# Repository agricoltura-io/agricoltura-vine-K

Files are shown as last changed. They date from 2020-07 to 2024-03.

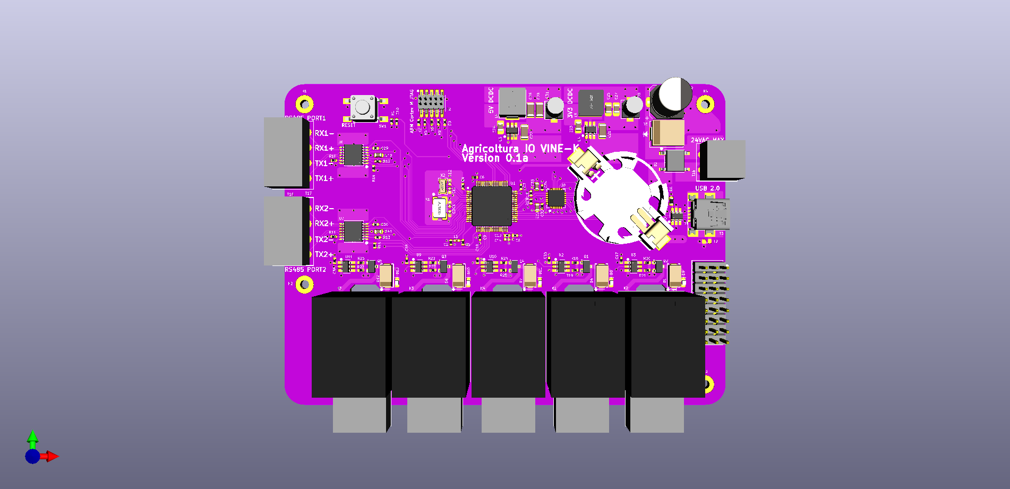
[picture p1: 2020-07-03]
PCB/agricoltura-vine-k/agricoltura-vine-k3D.png

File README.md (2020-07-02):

# agricoltura-vine-K
daisy chainable interface for relay control of high voltage devices for various agriculture applications, wired RS485 system, powered by 24VAC

Quick Specs:
- ST Microelectronics STM32F446RET6 ARM Cortex M4F 180MHZ MCU
- 5V Tolerant Analog Inputs
- 8x I2C interfaces
- 4x UART interface (via mux)
- 8x 5V digital IO ports
- 2x G5LE-14 DC5 SPDT Relays
- USB 2.0 connectivity
- RS485 port
- 24VAC power input
- 2A 3.3V DCDC Regulator, for supporting lots of sensors
- 2A 5V DCDC Regulator, for 5V IO and other devices

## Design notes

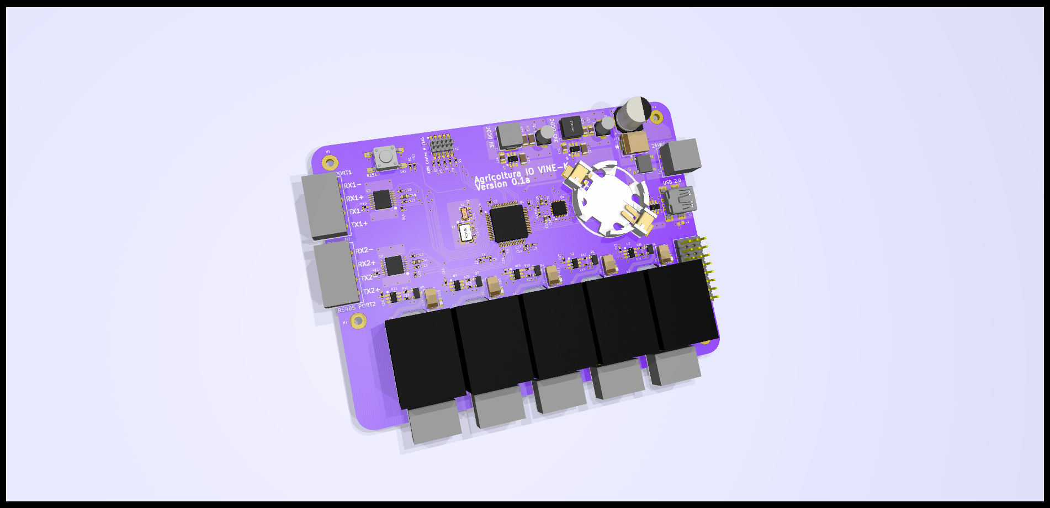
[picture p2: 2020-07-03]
PCB/agricoltura-vine-k/agricoltura-vine-k3DRay.png

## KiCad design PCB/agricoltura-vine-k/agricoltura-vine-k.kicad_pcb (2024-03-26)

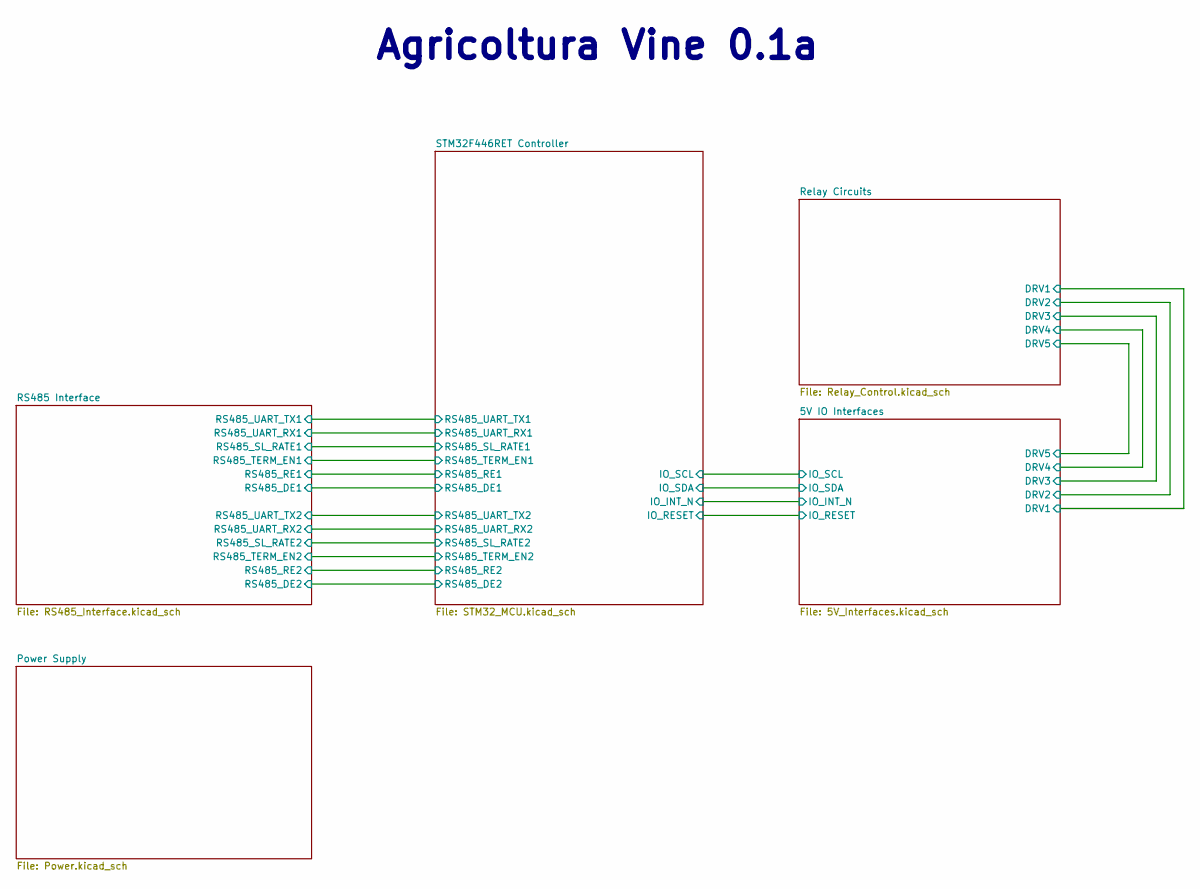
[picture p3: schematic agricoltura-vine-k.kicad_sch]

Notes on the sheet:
Agricoltura Vine 0.1a

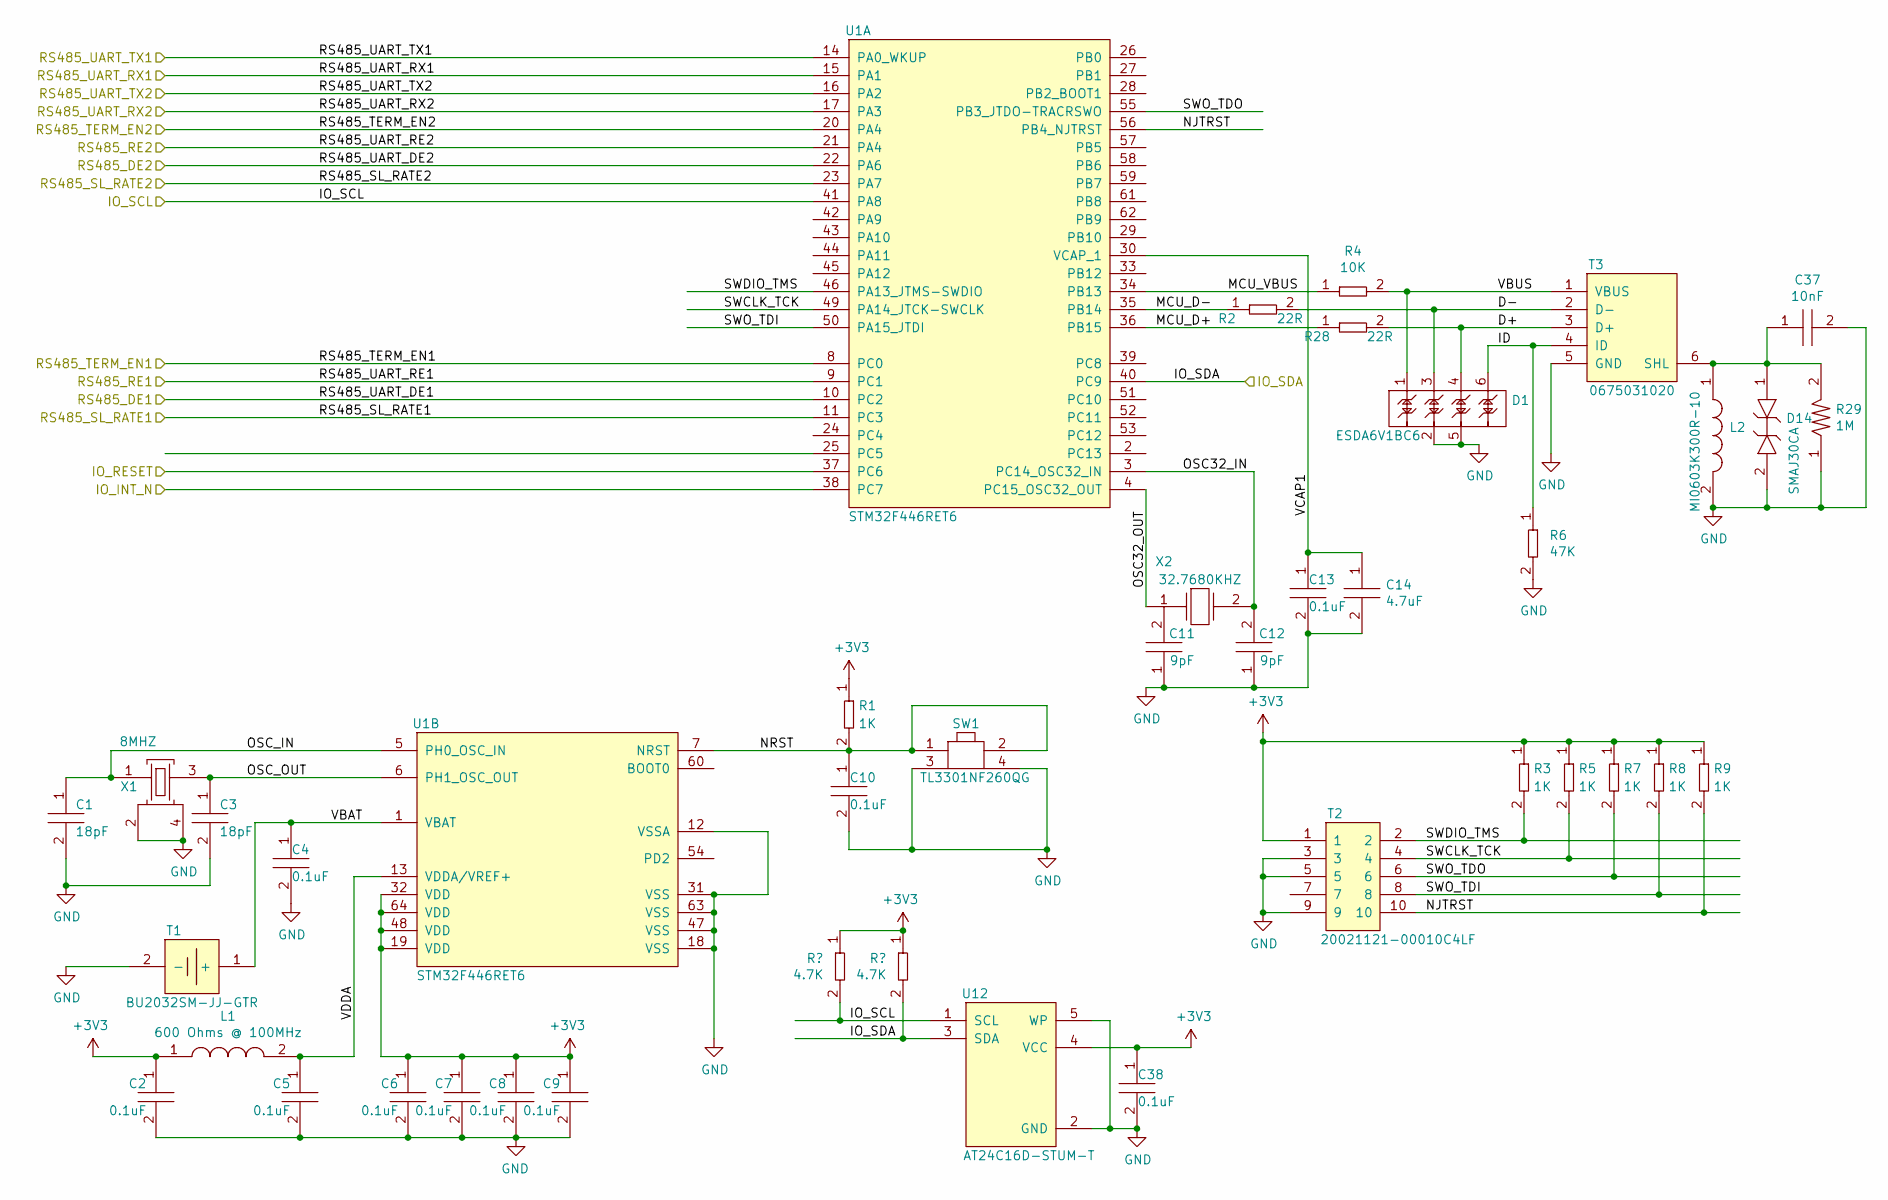
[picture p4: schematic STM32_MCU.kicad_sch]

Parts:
C1, C3: GCM1555C1H180GA16D; C0402; Tolerance 2%; Voltage 50V; MFR# GCM1555C1H180GA16D
C2, C4, C5, C6, C7, C8, C9, C10, C13, C38: C0402C104K9PACTU; R0402; Tolerance 10%; Voltage 6.3V; MFR# C0402C104K9PACTU
C11, C12: CL05C090CB5NNNC; C0402; Tolerance ±0.25pF; Voltage 50V; MFR# CL05C090CB5NNNC
C14: GRM155R60J475ME47D; C0402; Tolerance 20%; Voltage 6.3V; MFR# GRM155R60J475ME47D
C37: C0805C103KCRACAUTO; C0805; Tolerance 10%; Voltage 500V; MFR# C0805C103KCRACAUTO
D1: ESDA6V1BC6; SOT-23-6_Handsoldering; Tolerance *; Voltage 5V/6.1VBreakdown; MFR# ESDA6V1BC6
D14: SMAJ30CA; Tolerance *; Voltage 30V Clamp; MFR# SMAJ30CA
L1: BLM15HG601SN1D; Tolerance *; Voltage *; MFR# BLM15HG601SN1D
L2: MI0603K300R-10; Tolerance *; Voltage *; MFR# MI0603K300R-10
R1, R3, R5, R7, R8, R9: RC0402FR-071KL; R0402; Tolerance 1%; Voltage *; MFR# RC0402FR-071KL
R2, R28: RC0402FR-0722RL; R0402; Tolerance 1%; Voltage *; MFR# RC0402FR-0722RL
R4: RC0402FR-0710KL; R0402; Tolerance 1%; Voltage *; MFR# RC0402FR-0710KL
R6: RC0603FR-0747KL; R0603; Tolerance 1%; Voltage *; MFR# RC0603FR-0747KL
R29: RC1206FR-071ML; R1206; Tolerance 1%; Voltage *; MFR# RC1206FR-071ML
R30, R31: RC0402FR-074K7L; R0402; Tolerance 1%; Voltage *; MFR# RC0402FR-074K7L
SW1: TL3301NF260QG; Tolerance *; Voltage 12VDC; MFR# TL3301NF260QG
T1: BU2032SM-JJ-GTR; Tolerance *; Voltage 3.3V; MFR# BU2032SM-JJ-GTR
T2: 20021121-00010C4LF; Tolerance *; Voltage *; MFR# 20021121-00010C4LF
T3: 0675031020; USB_Mini-B; Tolerance *; Voltage 5V; MFR# 0675031020
U1: STM32F446RET6; Tolerance *; Voltage 1.7V ~ 3.6V; MFR# STM32F446RET6
U12: AT24C16D-STUM-T; SOT-23-5; Tolerance *; Voltage 3.3V; MFR# AT24C16D-STUM-T
X1: ABM3B-8.000MHZ-B2-T; ABM3B8.000MHZB2T; Tolerance *; Voltage *; MFR# ABM3B-8.000MHZ-B2-T
X2: ABS07-32.768KHZ-9-T; Tolerance *; Voltage *; MFR# ABS07-32.768KHZ-9-T

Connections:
+3V3: C2.1, C6.1, C7.1, C8.1, C9.1, C38.1, L1.1, R1.1, R3.1, R5.1, R7.1, R8.1, R9.1, R30.1, R31.1, T2.1, U1.19 (VDD), U1.32 (VDD), U1.48 (VDD), U1.64 (VDD), U12.4 (VCC); also elsewhere on the board
/5V IO Interfaces/IO_INT_N: U1.38 (PC7); also elsewhere on the board
/5V IO Interfaces/IO_RESET: U1.37 (PC6); also elsewhere on the board
/5V IO Interfaces/IO_SCL: R30.2, U1.41 (PA8), U12.1 (SCL); also elsewhere on the board
/5V IO Interfaces/IO_SDA: R31.2, U1.40 (PC9), U12.3 (SDA); also elsewhere on the board
/RS485 Interface/RS485_DE1: U1.10 (PC2); also elsewhere on the board
/RS485 Interface/RS485_DE2: U1.22 (PA6); also elsewhere on the board
/RS485 Interface/RS485_RE1: U1.9 (PC1); also elsewhere on the board
/RS485 Interface/RS485_RE2: U1.21 (PA4); also elsewhere on the board
/RS485 Interface/RS485_SL_RATE1: U1.11 (PC3); also elsewhere on the board
/RS485 Interface/RS485_SL_RATE2: U1.23 (PA7); also elsewhere on the board
/RS485 Interface/RS485_TERM_EN1: U1.8 (PC0); also elsewhere on the board
/RS485 Interface/RS485_TERM_EN2: U1.20 (PA4); also elsewhere on the board
/RS485 Interface/RS485_UART_RX1: U1.15 (PA1); also elsewhere on the board
/RS485 Interface/RS485_UART_RX2: U1.17 (PA3); also elsewhere on the board
/RS485 Interface/RS485_UART_TX1: U1.14 (PA0_WKUP); also elsewhere on the board
/RS485 Interface/RS485_UART_TX2: U1.16 (PA2); also elsewhere on the board
/STM32F446RET Controller/D+: D1.4, R28.2, T3.3 (D+)
/STM32F446RET Controller/D-: D1.3, R2.2, T3.2 (D-)
/STM32F446RET Controller/ID: D1.6, R6.1, T3.4 (ID)
/STM32F446RET Controller/MCU_D+: R28.1, U1.36 (PB15)
/STM32F446RET Controller/MCU_D-: R2.1, U1.35 (PB14)
/STM32F446RET Controller/MCU_VBUS: R4.1, U1.34 (PB13)
/STM32F446RET Controller/NJTRST: R9.2, T2.10, U1.56 (PB4_NJTRST)
/STM32F446RET Controller/NRST: C10.1, R1.2, SW1.1, SW1.2, U1.7 (NRST)
/STM32F446RET Controller/OSC32_IN: C12.2, U1.3 (PC14_OSC32_IN), X2.2
/STM32F446RET Controller/OSC32_OUT: U1.4 (PC15_OSC32_OUT), X2.1
/STM32F446RET Controller/OSC_IN: C1.1, U1.5 (PH0_OSC_IN), X1.1
/STM32F446RET Controller/OSC_OUT: C3.1, U1.6 (PH1_OSC_OUT), X1.3
/STM32F446RET Controller/SWCLK_TCK: R5.2, T2.4, U1.49 (PA14_JTCK-SWCLK)
/STM32F446RET Controller/SWDIO_TMS: R3.2, T2.2, U1.46 (PA13_JTMS-SWDIO)
/STM32F446RET Controller/SWO_TDI: R8.2, T2.8, U1.50 (PA15_JTDI)
/STM32F446RET Controller/SWO_TDO: R7.2, T2.6, U1.55 (PB3_JTDO-TRACRSWO)
/STM32F446RET Controller/VBAT: C4.1, T1.1 (+), U1.1 (VBAT)
/STM32F446RET Controller/VBUS: D1.1, R4.2, T3.1 (VBUS)
/STM32F446RET Controller/VCAP1: C13.1, C14.1, U1.30 (VCAP_1)
/STM32F446RET Controller/VDDA: C5.1, L1.2, U1.13 (VDDA/VREF+)
GND: C1.2, C2.2, C3.2, C4.2, C5.2, C6.2, C7.2, C8.2, C9.2, C10.2, C11.1, C12.1, C13.2, C14.2, C37.2, C38.2, D1.2, D1.5, D14.2, L2.2, R6.2, R29.1, SW1.3, SW1.4, T1.2 (-), T2.3, T2.5, T2.9, T3.5 (GND), U1.12 (VSSA), U1.18 (VSS), U1.31 (VSS), U1.47 (VSS), U1.63 (VSS), U12.2 (GND), U12.5 (WP), X1.2, X1.4; also elsewhere on the board
unnamed: C37.1, D14.1, L2.1, R29.2, T3.6 (SHL)

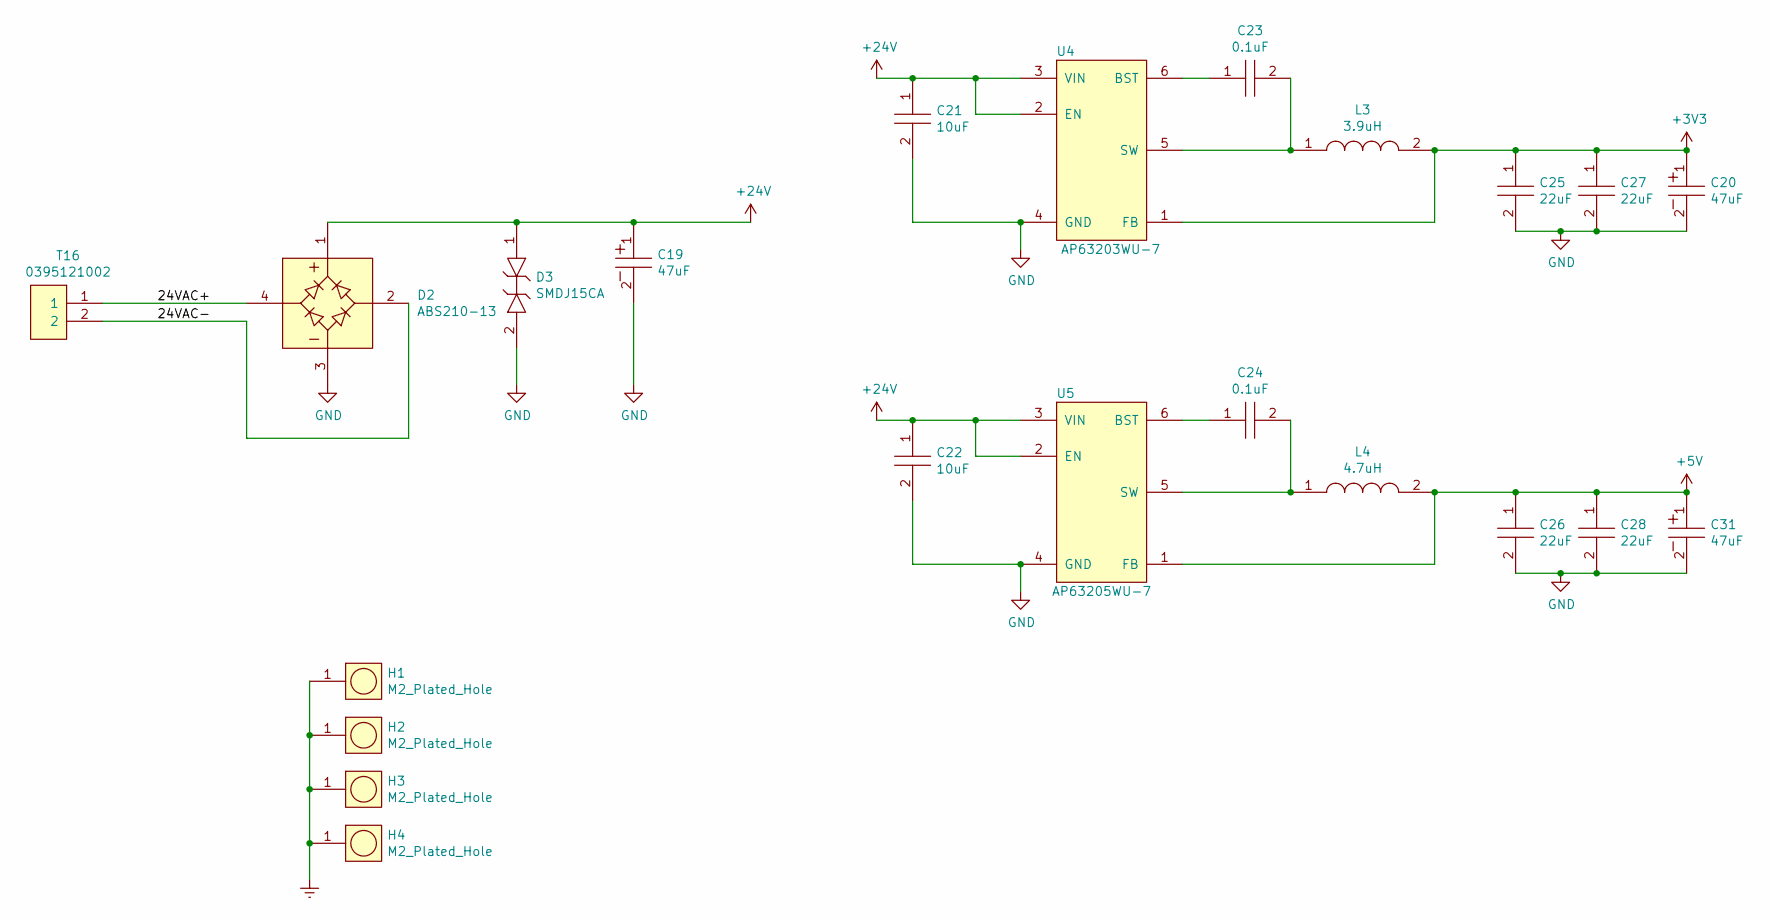
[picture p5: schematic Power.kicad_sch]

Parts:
C19: UUQ1H470MCL1GS; CP_Elec_8x10; Tolerance 20%; Voltage 50V; MFR# UUQ1H470MCL1GS
C20, C31: UCM1C470MCL1GS; Tolerance 20%; Voltage 16V; MFR# UCM1C470MCL1GS
C21, C22: GRT31CR61H106KE01L; C1206; Tolerance 10%; Voltage 50V; MFR# GRT31CR61H106KE01L
C23: C0805C104M5RACTU; C0805; Tolerance 20%; Voltage 50V; MFR# C0805C104M5RACTU
C24: C2012X7R2A104K125AA; C0805; Tolerance 10%; Voltage 100V; MFR# C2012X7R2A104K125AA
C25, C27: GRM21BD70J226ME44L; C0805; Tolerance 20%; Voltage 6.3v; MFR# GRM21BD70J226ME44L
C26, C28: GRT31CC81C226KE01L; C1206; Tolerance 10%; Voltage 16V; MFR# GRT31CC81C226KE01L
D2: ABS210-13; Tolerance *; Voltage 1KV 2A; MFR# ABS210-13
D3: SMDJ15CA; Tolerance *; Voltage 24V Clamp; MFR# SMDJ15CA
H1, H2, H3, H4: M2_Plated_Hole; M2_HOLE; Tolerance *; Voltage *; MFR# *
L3: ASPI-0628-3R9M-T1; Tolerance 20%; Voltage *; MFR# ASPI-0628-3R9M-T1
L4: SRP6540-4R7M; Tolerance 20%; Voltage *; MFR# SRP6540-4R7M
T16: 0395121002; Tolerance *; Voltage 300V; MFR# 0395121002
U4: AP63203WU-7; SOT-23-6_Handsoldering; Tolerance *; Voltage 32V, 3.3V; MFR# AP63203WU-7
U5: AP63205WU-7; SOT-23-6_Handsoldering; Tolerance *; Voltage 32V, 5V; MFR# AP63205WU-7

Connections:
+3V3: C20.1, C25.1, C27.1, L3.2, U4.1 (FB); also elsewhere on the board
+24V: C19.1, C21.1, C22.1, D2.1, D3.1, U4.2 (EN), U4.3 (VIN), U5.2 (EN), U5.3 (VIN)
/Power Supply/24VAC+: D2.4, T16.1
/Power Supply/24VAC-: D2.2, T16.2
Earth: H1.1, H2.1, H3.1, H4.1
GND: C19.2, C20.2, C21.2, C22.2, C25.2, C26.2, C27.2, C28.2, C31.2, D2.3, D3.2, U4.4 (GND), U5.4 (GND); also elsewhere on the board
unnamed: C23.1, U4.6 (BST)
unnamed: C23.2, L3.1, U4.5 (SW)
unnamed: C24.1, U5.6 (BST)
unnamed: C24.2, L4.1, U5.5 (SW)

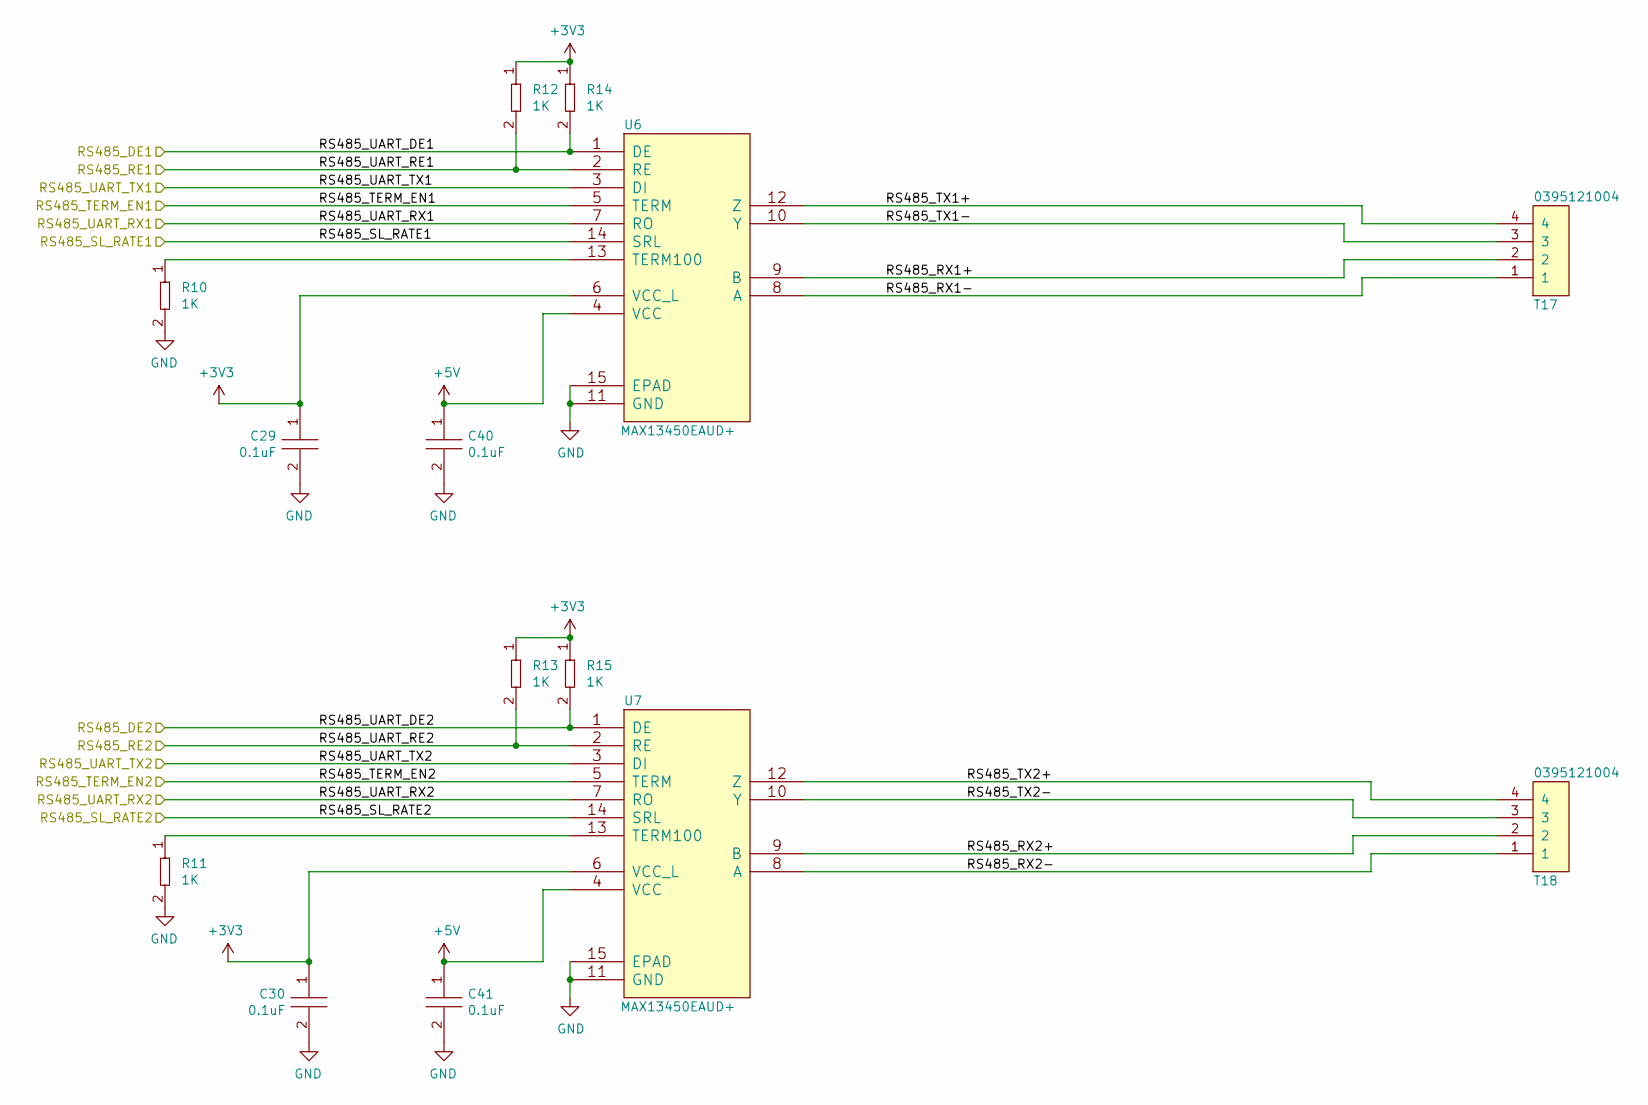
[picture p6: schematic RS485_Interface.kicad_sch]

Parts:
C29, C30: C0402C104K9PACTU; R0402; Tolerance 10%; Voltage 6.3V; MFR# C0402C104K9PACTU
C40, C41: CGA3E2X7R1H104K080AA; C0603; Tolerance 10%; Voltage 50V; MFR# CGA3E2X7R1H104K080AA
R10, R11, R12, R13, R14, R15: RC0402FR-071KL; R0402; Tolerance 1%; Voltage *; MFR# RC0402FR-071KL
T17, T18: 0395121004; Tolerance *; Voltage 300V; MFR# 0395121004
U6, U7: MAX13450EAUD+; MAX13450EAUD&plus_; Tolerance *; Voltage 4.75V ~ 5.25V; MFR# MAX13450EAUD+

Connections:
+3V3: C29.1, C30.1, R12.1, R13.1, R14.1, R15.1, U6.6 (VCC_L), U7.6 (VCC_L); also elsewhere on the board
/RS485 Interface/RS485_DE1: R14.2, U6.1 (DE); also elsewhere on the board
/RS485 Interface/RS485_DE2: R15.2, U7.1 (DE); also elsewhere on the board
/RS485 Interface/RS485_RE1: R12.2, U6.2 (RE); also elsewhere on the board
/RS485 Interface/RS485_RE2: R13.2, U7.2 (RE); also elsewhere on the board
/RS485 Interface/RS485_RX1+: T17.2, U6.9 (B)
/RS485 Interface/RS485_RX1-: T17.1, U6.8 (A)
/RS485 Interface/RS485_RX2+: T18.2, U7.9 (B)
/RS485 Interface/RS485_RX2-: T18.1, U7.8 (A)
/RS485 Interface/RS485_SL_RATE1: U6.14 (SRL); also elsewhere on the board
/RS485 Interface/RS485_SL_RATE2: U7.14 (SRL); also elsewhere on the board
/RS485 Interface/RS485_TERM_EN1: U6.5 (TERM); also elsewhere on the board
/RS485 Interface/RS485_TERM_EN2: U7.5 (TERM); also elsewhere on the board
/RS485 Interface/RS485_TX1+: T17.4, U6.12 (Z)
/RS485 Interface/RS485_TX1-: T17.3, U6.10 (Y)
/RS485 Interface/RS485_TX2+: T18.4, U7.12 (Z)
/RS485 Interface/RS485_TX2-: T18.3, U7.10 (Y)
/RS485 Interface/RS485_UART_RX1: U6.7 (RO); also elsewhere on the board
/RS485 Interface/RS485_UART_RX2: U7.7 (RO); also elsewhere on the board
/RS485 Interface/RS485_UART_TX1: U6.3 (DI); also elsewhere on the board
/RS485 Interface/RS485_UART_TX2: U7.3 (DI); also elsewhere on the board
GND: C29.2, C30.2, C40.2, C41.2, R10.2, R11.2, U6.11 (GND), U6.15 (EPAD), U7.11 (GND), U7.15 (EPAD); also elsewhere on the board
unnamed: R10.1, U6.13 (TERM100)
unnamed: R11.1, U7.13 (TERM100)

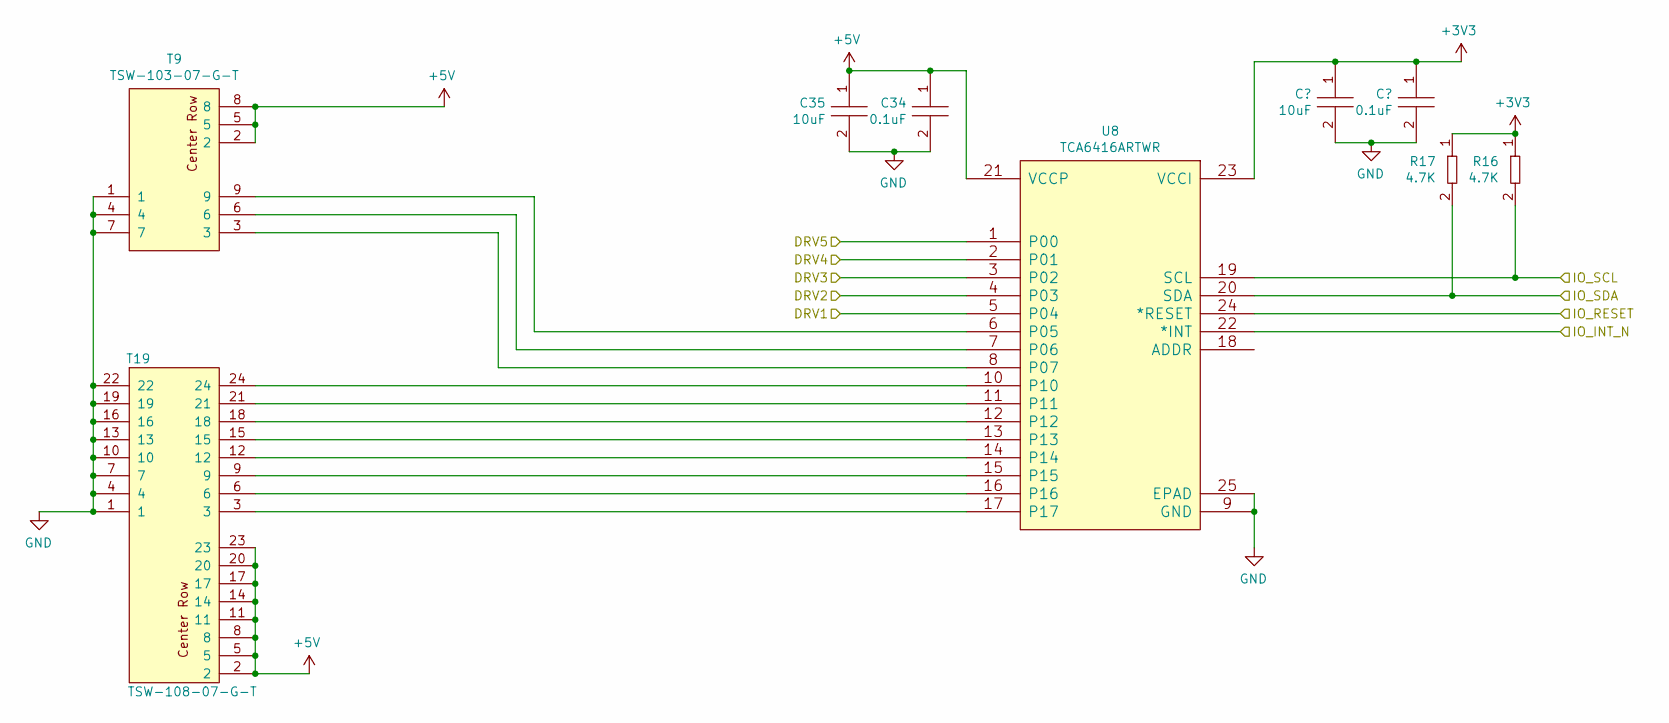
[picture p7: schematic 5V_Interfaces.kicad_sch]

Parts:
C32, C34: C0402C104K9PACTU; R0402; Tolerance 10%; Voltage 6.3V; MFR# C0402C104K9PACTU
C33, C35: GRM188R61A106KE69J; C0603; Tolerance 10%; Voltage 10V; MFR# GRM188R61A106KE69J
R16, R17: RC0402FR-074K7L; R0402; Tolerance 1%; Voltage *; MFR# RC0402FR-074K7L
T9: TSW-103-07-G-T; Tolerance *; Voltage *; MFR# TSW-103-07-G-T
T19: TSW-108-07-G-T; Tolerance *; Voltage *; MFR# TSW-108-07-G-T
U8: TCA6416ARTWR; Tolerance *; Voltage 1.65V ~ 5.5V; MFR# TCA6416ARTWR

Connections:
+3V3: C32.1, C33.1, R16.1, R17.1, U8.23 (VCCI); also elsewhere on the board
/5V IO Interfaces/DRV1: U8.5 (P04); also elsewhere on the board
/5V IO Interfaces/DRV2: U8.4 (P03); also elsewhere on the board
/5V IO Interfaces/DRV3: U8.3 (P02); also elsewhere on the board
/5V IO Interfaces/DRV4: U8.2 (P01); also elsewhere on the board
/5V IO Interfaces/DRV5: U8.1 (P00); also elsewhere on the board
/5V IO Interfaces/IO_INT_N: U8.22 (*INT); also elsewhere on the board
/5V IO Interfaces/IO_RESET: U8.24 (*RESET); also elsewhere on the board
/5V IO Interfaces/IO_SCL: R16.2, U8.19 (SCL); also elsewhere on the board
/5V IO Interfaces/IO_SDA: R17.2, U8.20 (SDA); also elsewhere on the board
GND: C32.2, C33.2, C34.2, C35.2, T9.1, T9.4, T9.7, T19.1, T19.4, T19.7, T19.10, T19.13, T19.16, T19.19, T19.22, U8.9 (GND), U8.25 (EPAD); also elsewhere on the board
unnamed: T9.3, U8.8 (P07)
unnamed: T9.6, U8.7 (P06)
unnamed: T9.9, U8.6 (P05)
unnamed: T19.3, U8.17
unnamed: T19.6, U8.16
unnamed: T19.9, U8.15
unnamed: T19.12, U8.14
unnamed: T19.15, U8.13
unnamed: T19.18, U8.12
unnamed: T19.21, U8.11
unnamed: T19.24, U8.10

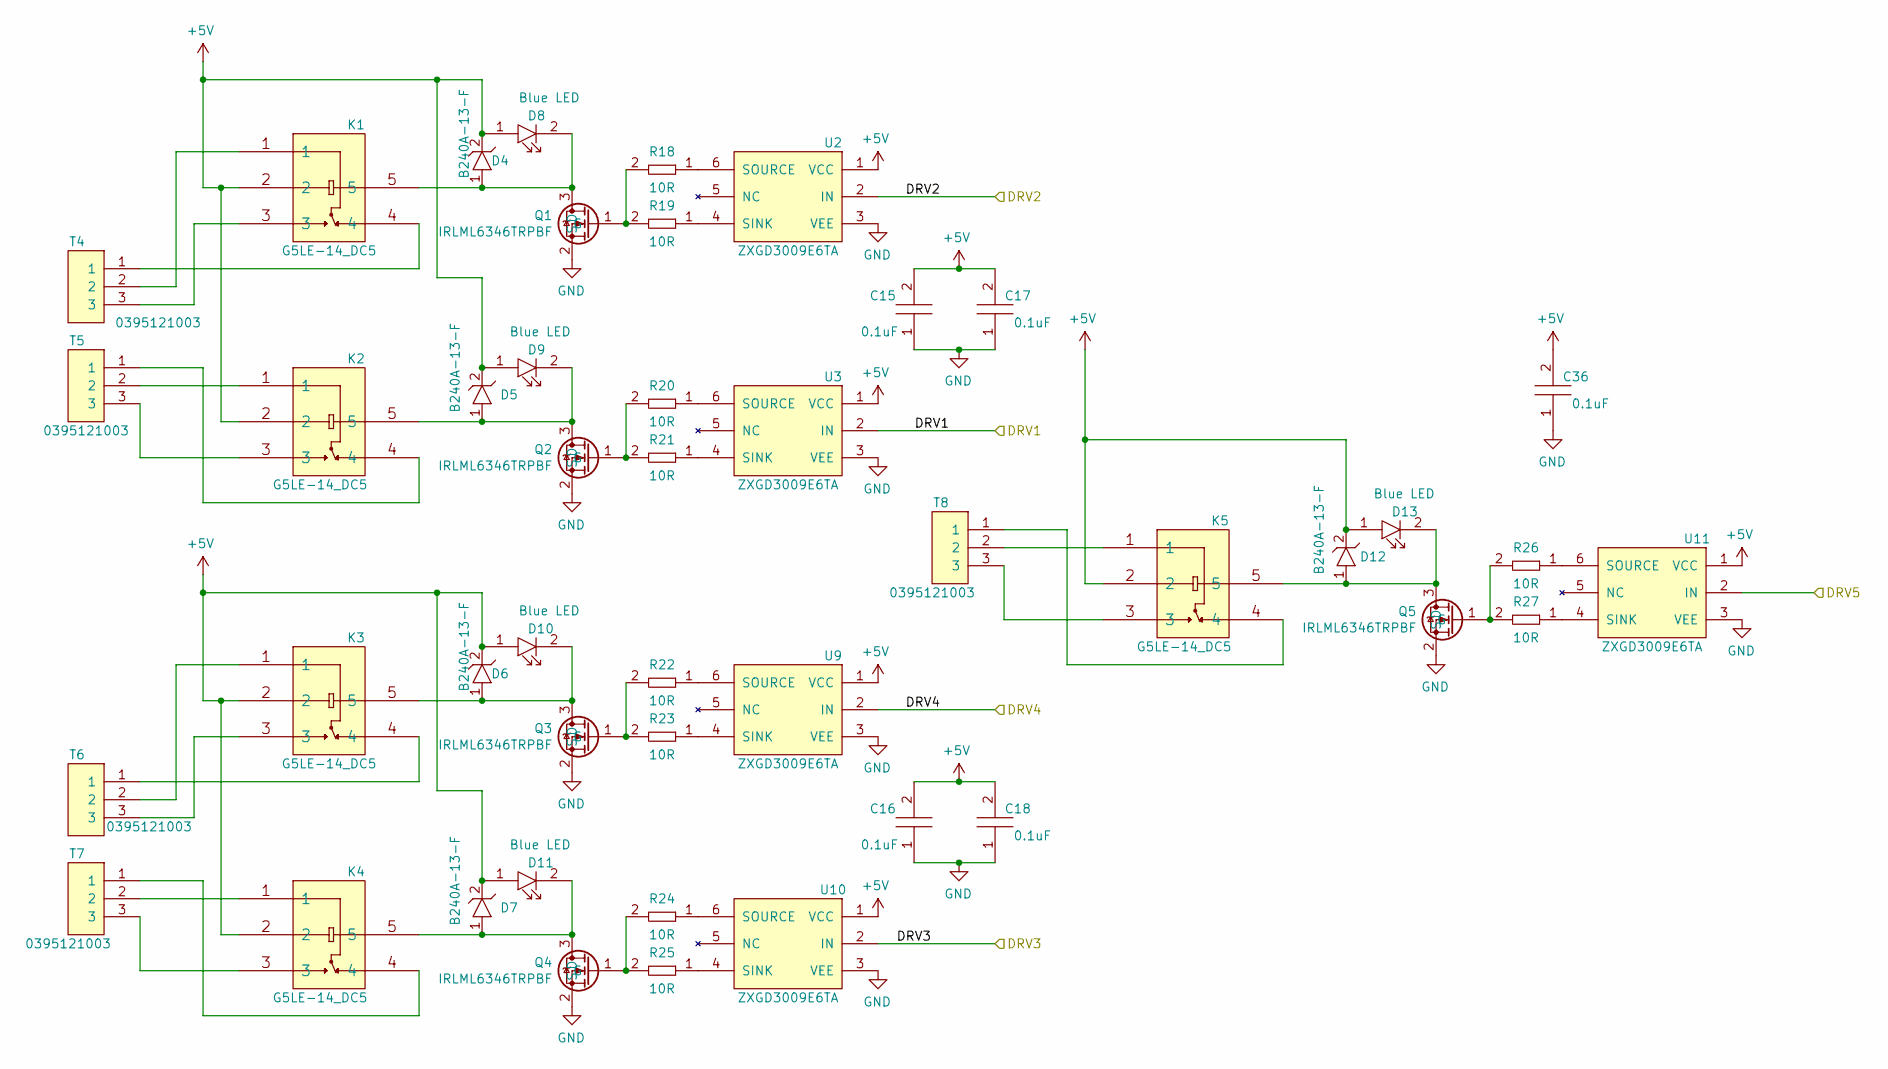
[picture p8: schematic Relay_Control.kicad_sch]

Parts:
C15, C16, C17, C18, C36: C0402C104K9PACTU; R0402; Tolerance 10%; Voltage 6.3V; MFR# C0402C104K9PACTU
D4, D5, D6, D7, D12: B240A-13-F; Tolerance *; Voltage 40V; MFR# B240A-13-F
D8, D9, D10, D11, D13: LTST-C194TBKT; LED0603; Tolerance *; Voltage 3.3V; MFR# LTST-C194TBKT
K1, K2, K3, K4, K5: G5LE-14_DC5; Tolerance *; Voltage 5VDC Coil, 250VAC, 125VDC - Max; MFR# G5LE-14 DC5
Q1, Q2, Q3, Q4, Q5: IRLML6346TRPBF; SOT-23; Tolerance *; Voltage 30V; MFR# IRLML6346TRPBF
R18, R19, R20, R21, R22, R23, R24, R25, R26, R27: RC0402FR-0710RL; R0402; Tolerance 1%; Voltage *; MFR# RC0402FR-0710RL
T4, T5, T6, T7, T8: 0395121003; Tolerance *; Voltage 300V; MFR# 0395121003
U2, U3, U9, U10, U11: ZXGD3009E6TA; SOT-23-6_Handsoldering; Tolerance *; Voltage 40V; MFR# ZXGD3009E6TA

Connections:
/5V IO Interfaces/DRV1: U3.2 (IN); also elsewhere on the board
/5V IO Interfaces/DRV2: U2.2 (IN); also elsewhere on the board
/5V IO Interfaces/DRV3: U10.2 (IN); also elsewhere on the board
/5V IO Interfaces/DRV4: U9.2 (IN); also elsewhere on the board
/5V IO Interfaces/DRV5: U11.2 (IN); also elsewhere on the board
GND: C15.1, C16.1, C17.1, C18.1, C36.1, Q1.2 (S), Q2.2 (S), Q3.2 (S), Q4.2 (S), Q5.2 (S), U2.3 (VEE), U3.3 (VEE), U9.3 (VEE), U10.3 (VEE), U11.3 (VEE); also elsewhere on the board
unnamed: D4.1, D8.2, K1.5, Q1.3 (D)
unnamed: D5.1, D9.2, K2.5, Q2.3 (D)
unnamed: D6.1, D10.2, K3.5, Q3.3 (D)
unnamed: D7.1, D11.2, K4.5, Q4.3 (D)
unnamed: D12.1, D13.2, K5.5, Q5.3 (D)
unnamed: K1.1, T4.2
unnamed: K1.3, T4.3
unnamed: K1.4, T4.1
unnamed: K2.1, T5.2
unnamed: K2.3, T5.3
unnamed: K2.4, T5.1
unnamed: K3.1, T6.2
unnamed: K3.3, T6.3
unnamed: K3.4, T6.1
unnamed: K4.1, T7.2
unnamed: K4.3, T7.3
unnamed: K4.4, T7.1
unnamed: K5.1, T8.2
unnamed: K5.3, T8.3
unnamed: K5.4, T8.1
unnamed: Q1.1 (G), R18.2, R19.2
unnamed: Q2.1 (G), R20.2, R21.2
unnamed: Q3.1 (G), R22.2, R23.2
unnamed: Q4.1 (G), R24.2, R25.2
unnamed: Q5.1 (G), R26.2, R27.2
unnamed: R18.1, U2.6 (SOURCE)
unnamed: R19.1, U2.4 (SINK)
unnamed: R20.1, U3.6 (SOURCE)
unnamed: R21.1, U3.4 (SINK)
unnamed: R22.1, U9.6 (SOURCE)
unnamed: R23.1, U9.4 (SINK)
unnamed: R24.1, U10.6 (SOURCE)
unnamed: R25.1, U10.4 (SINK)
unnamed: R26.1, U11.6 (SOURCE)
unnamed: R27.1, U11.4 (SINK)

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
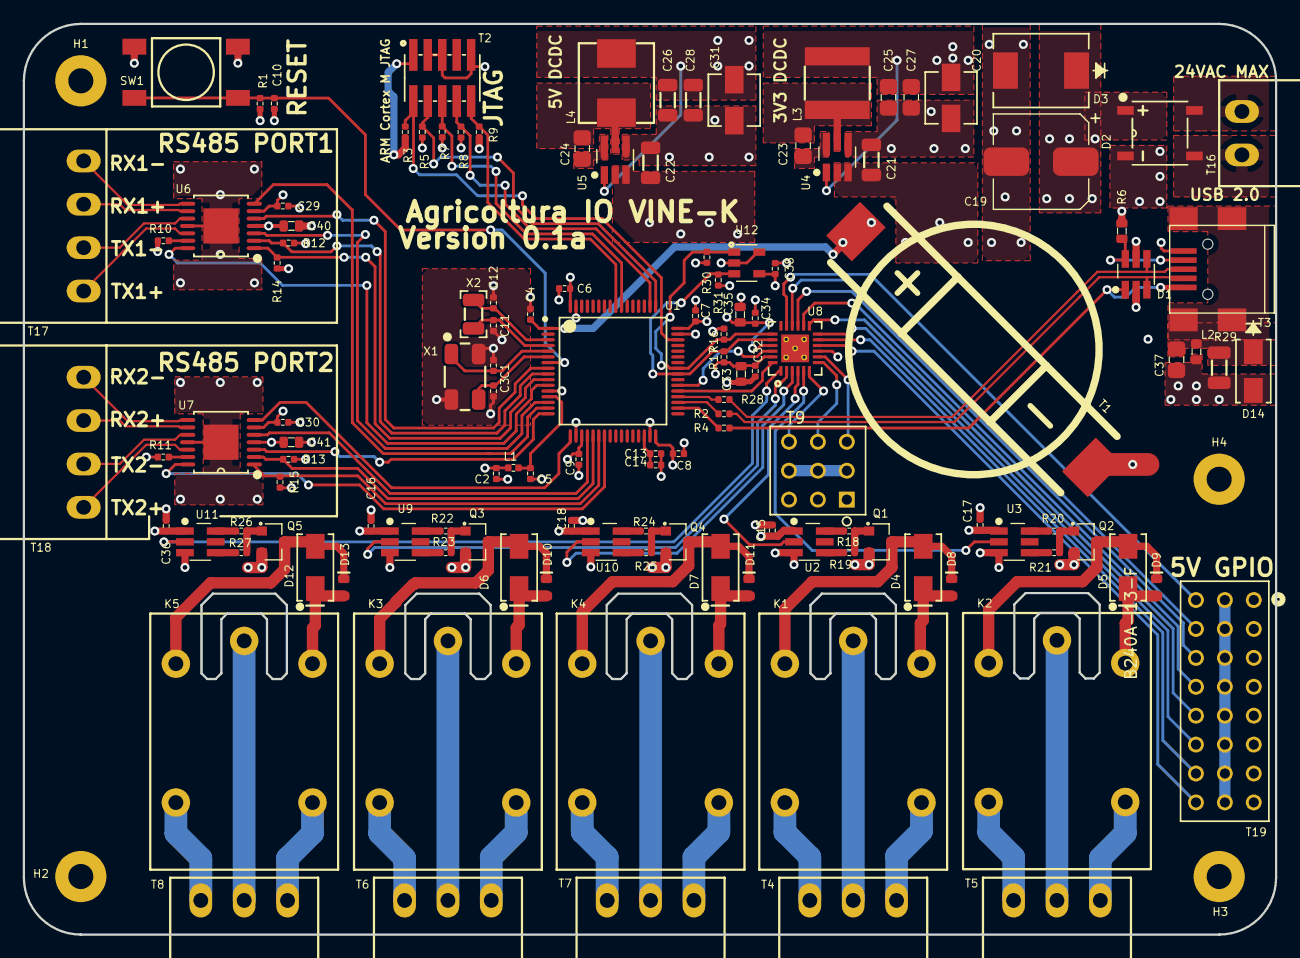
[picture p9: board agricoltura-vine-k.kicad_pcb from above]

Board: 4 copper layers, 110.0 x 80.0 mm, 131 parts (0 on the bottom side), 109 nets.

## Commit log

2020-07-02 Project Created and Datasheets
    Project Created based on Vine project, added collection of datasheets.
    [5V_Interfaces.sch, Power.sch, RS485_Interface.sch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]
2020-07-02 Relay and Board
    Relay circuits added and exported to PCB
    [5V_Interfaces.sch, Relay_Control.sch]
2020-07-03 PCB Routing PRogress
    5th relay added to schematic, PCB section with Relays routed, still need to connecto IO expander channels.
    [Relay_Control.sch, STM32_MCU.sch, agricoltura-vine-k.kicad_pcb]
2020-07-03 Finished
    PCB routing complete, up for review before fab.
    [5V_Interfaces.sch, RS485_Interface.sch, Relay_Control.sch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]
2020-07-17 Boot Mode Guide
    guide for STM32 boot modes added
2020-07-24 EEPROM
    added EEPROM to IO expander serial port. Broke out remaining IO expander pins to header. Adjusted silkscreen labeling and reset button position to match the other Vine.
    [5V_Interfaces.sch, Power.sch, STM32_MCU.sch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]
2021-02-08 PCB Tweaks
    PCB tweaked for packaging in water resistant housing for greenhouse deployment
    [Relay_Control.sch, agricoltura-vine-k.kicad_pcb]
2024-03-26 kICAD 8
    Projected updated to KiCAD 8
    [5V_Interfaces.kicad_sch, Power.kicad_sch, RS485_Interface.kicad_sch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]

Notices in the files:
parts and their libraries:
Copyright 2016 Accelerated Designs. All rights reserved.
